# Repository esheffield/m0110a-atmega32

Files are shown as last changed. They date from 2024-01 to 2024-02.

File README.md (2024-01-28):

# m0110a-atmega32

## Background
This repo contains the schematic, pcb, and code for a drop-in replacement module for the controller in the Macintosh Plus m0110a keyboard. This controller is often damage or destroyed thanks to Apple's bizarre decision to use a cable that that *looks* like a telephone handset cable and uses the same connectors but is *wired differently*. If a user tried to use a phone handset cable in place of the original, this would feed reversed polarity power to the controller and kill it.

This replacement is based on the ATMega32 microcontroller. This controller was chosen due to the high number of GPIO pins available. The keyboard uses most of these, with a 10 x 8 matrix, four additional lines for Shift, Caps Lock, Command, and Option keys, and two communication lines for a total of 24 required lines. To aid in debugging if necessary in the future, the dedicated serial TxD and RxD lines are reserved and broken out to an optional header on the module.

The module also provides a standard 6-pin ISP connection. Thanks to the layout of keyboard, it's possible to access the ISP and Serial headers by removing the spacebar.

## Limitations
At this time, this module will only work in the m0110a keyboard as included with the Macintosh Plus. I don't know if the 128 / 512 keyboard and numeric keypad use the same controller. I understand that the keypad in particular has to act as a intermediary between the keyboard and Mac. I expect this work could be adapted, but at the least would require updated code if not changes to the hardware itself.

## License

The design and code are licensed under Apache 2.0.

## Attribution and Thanks

The code for communication with the Macintosh is based on the work of Tomasz Rękawek (https://github.com/trekawek), specifically his project adapting a PS2 keyboard to a Mac Plus (https://github.com/trekawek/mac-plus-ps2). Many thanks to Tomasz for his valuable work!

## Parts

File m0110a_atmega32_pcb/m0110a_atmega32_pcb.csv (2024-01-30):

# | Reference | Qty | Value | Footprint | DNP
1 | C1, C2 | 2 | 18p | Capacitor_SMD:C_0201_0603Metric
2 | C3 | 1 | 1u | Capacitor_SMD:C_0201_0603Metric
3 | J1 | 1 | Conn_01x40_Pin | m0110a:Conn_2.54_W15.24mm
4 | J2 | 1 | ISP | Connector_PinHeader_2.54mm:PinHeader_2x03_P2.54mm_Vertical
5 | J3 | 1 | Serial | Connector_PinHeader_2.54mm:PinHeader_1x02_P2.54mm_Vertical
6 | R1 | 1 | 4k7 | Resistor_SMD:R_0201_0603Metric
7 | U2 | 1 | ATmega32A-M | Package_DFN_QFN:QFN-44-1EP_7x7mm_P0.5mm_EP5.2x5.2mm
8 | Y1 | 1 | 8 MHz | Crystal:Crystal_SMD_5032-2Pin_5.0x3.2mm

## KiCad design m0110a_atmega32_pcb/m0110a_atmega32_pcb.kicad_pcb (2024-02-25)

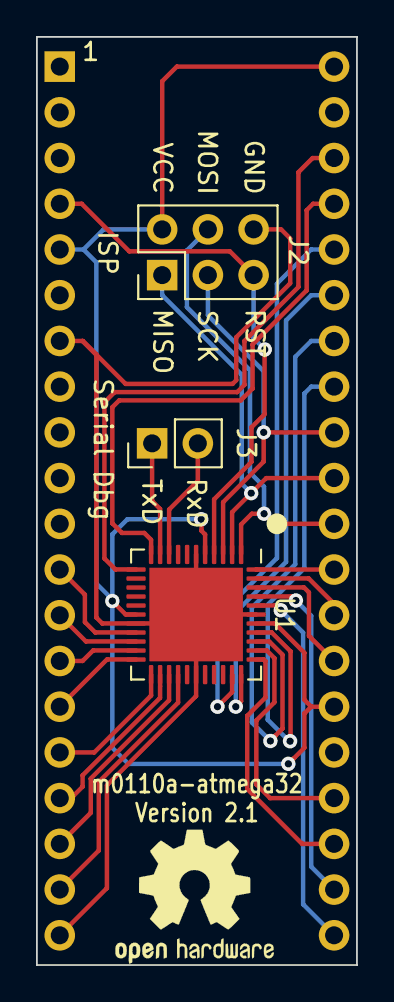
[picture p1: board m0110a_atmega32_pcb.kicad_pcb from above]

Board: 2 copper layers, 17.8 x 51.6 mm, 4 parts (0 on the bottom side), 29 nets.

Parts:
J1: Conn_01x40_Pin; Header_2.54_W15.24mm
J2: ISP; PinHeader_2x03_P2.54mm_Vertical
J3: Serial; PinHeader_1x02_P2.54mm_Vertical
U1: ATmega32A-M; QFN-44-1EP_7x7mm_P0.5mm_EP5.2x5.2mm

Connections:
+5V: J1.5, J1.26, J1.40, J2.2, U1.5 (VCC), U1.17 (VCC), U1.38 (VCC)
/CMD: J1.36, U1.32 (PA5)
/COL0: J1.19, U1.26 (PC7)
/COL1: J1.18, U1.25 (PC6)
/COL2: J1.17, U1.24 (PC5)
/COL3: J1.16, U1.23 (PC4)
/COL4: J1.15, U1.22 (PC3)
/COL5: J1.14, U1.21 (PC2)
/COL6: J1.13, U1.20 (PC1)
/COL7: J1.12, U1.19 (PC0)
/KB_CLK: J1.37, U1.11 (PD2)
/KB_DATA: J1.38, U1.12 (PD3)
/LOCK: J1.24, U1.35 (PA2)
/OPT: J1.35, U1.33 (PA4)
/ROW0: J1.21, U1.40 (PB0)
/ROW1: J1.22, U1.41 (PB1)
/ROW2: J1.27, U1.42 (PB2)
/ROW3: J1.28, U1.43 (PB3)
/ROW4: J1.29, U1.44 (PB4)
/ROW5: J1.30, J2.4, U1.1 (PB5)
/ROW6: J1.31, J2.1, U1.2 (PB6)
/ROW7: J1.32, J2.3, U1.3 (PB7)
/ROW8: J1.33, U1.37 (PA0)
/ROW9: J1.34, U1.36 (PA1)
/RXD: J3.2, U1.9 (PD0)
/SHIFT: J1.23, U1.34 (PA3)
/TXD: J3.1, U1.10 (PD1)
GNDREF: J1.7, J1.20, J2.6, U1.6 (GND), U1.18 (GND), U1.28 (GND), U1.39 (GND), U1.45 (GND)
RESET: J1.4, J2.5, U1.4 (~RESET)

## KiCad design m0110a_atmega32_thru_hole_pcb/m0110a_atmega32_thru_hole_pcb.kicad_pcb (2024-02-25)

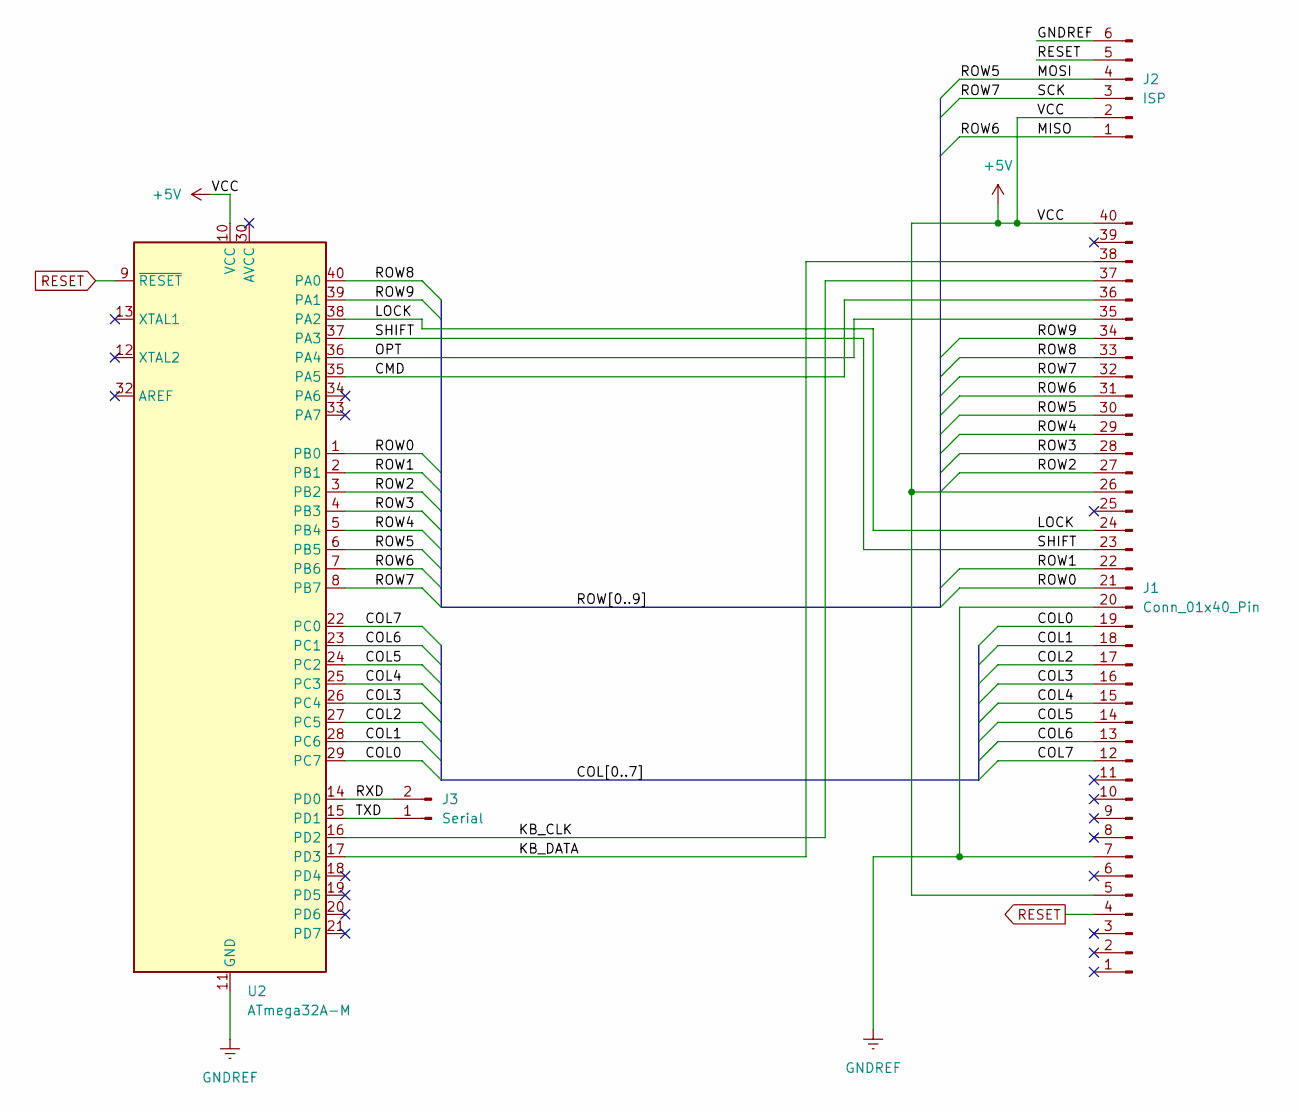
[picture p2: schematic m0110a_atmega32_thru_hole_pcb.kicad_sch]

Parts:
J1: Conn_01x40_Pin; Header_2.54_W15.24mm
J2: ISP; PinHeader_2x03_P2.54mm_Vertical
J3: Serial; PinHeader_1x02_P2.54mm_Vertical
U2: ATmega32A-M; DIP-40_W15.24mm

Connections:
+5V: J1.5, J1.26, J1.40, J2.2, U2.10 (VCC)
/CMD: J1.36, U2.35 (PA5)
/COL0: J1.19, U2.29 (PC7)
/COL1: J1.18, U2.28 (PC6)
/COL2: J1.17, U2.27 (PC5)
/COL3: J1.16, U2.26 (PC4)
/COL4: J1.15, U2.25 (PC3)
/COL5: J1.14, U2.24 (PC2)
/COL6: J1.13, U2.23 (PC1)
/COL7: J1.12, U2.22 (PC0)
/KB_CLK: J1.37, U2.16 (PD2)
/KB_DATA: J1.38, U2.17 (PD3)
/LOCK: J1.24, U2.38 (PA2)
/OPT: J1.35, U2.36 (PA4)
/ROW0: J1.21, U2.1 (PB0)
/ROW1: J1.22, U2.2 (PB1)
/ROW2: J1.27, U2.3 (PB2)
/ROW3: J1.28, U2.4 (PB3)
/ROW4: J1.29, U2.5 (PB4)
/ROW5: J1.30, J2.4, U2.6 (PB5)
/ROW6: J1.31, J2.1, U2.7 (PB6)
/ROW7: J1.32, J2.3, U2.8 (PB7)
/ROW8: J1.33, U2.40 (PA0)
/ROW9: J1.34, U2.39 (PA1)
/RXD: J3.2, U2.14 (PD0)
/SHIFT: J1.23, U2.37 (PA3)
/TXD: J3.1, U2.15 (PD1)
GNDREF: J1.7, J1.20, J2.6, U2.11 (GND), U2.31 (GND)
RESET: J1.4, J2.5, U2.9 (~RESET)

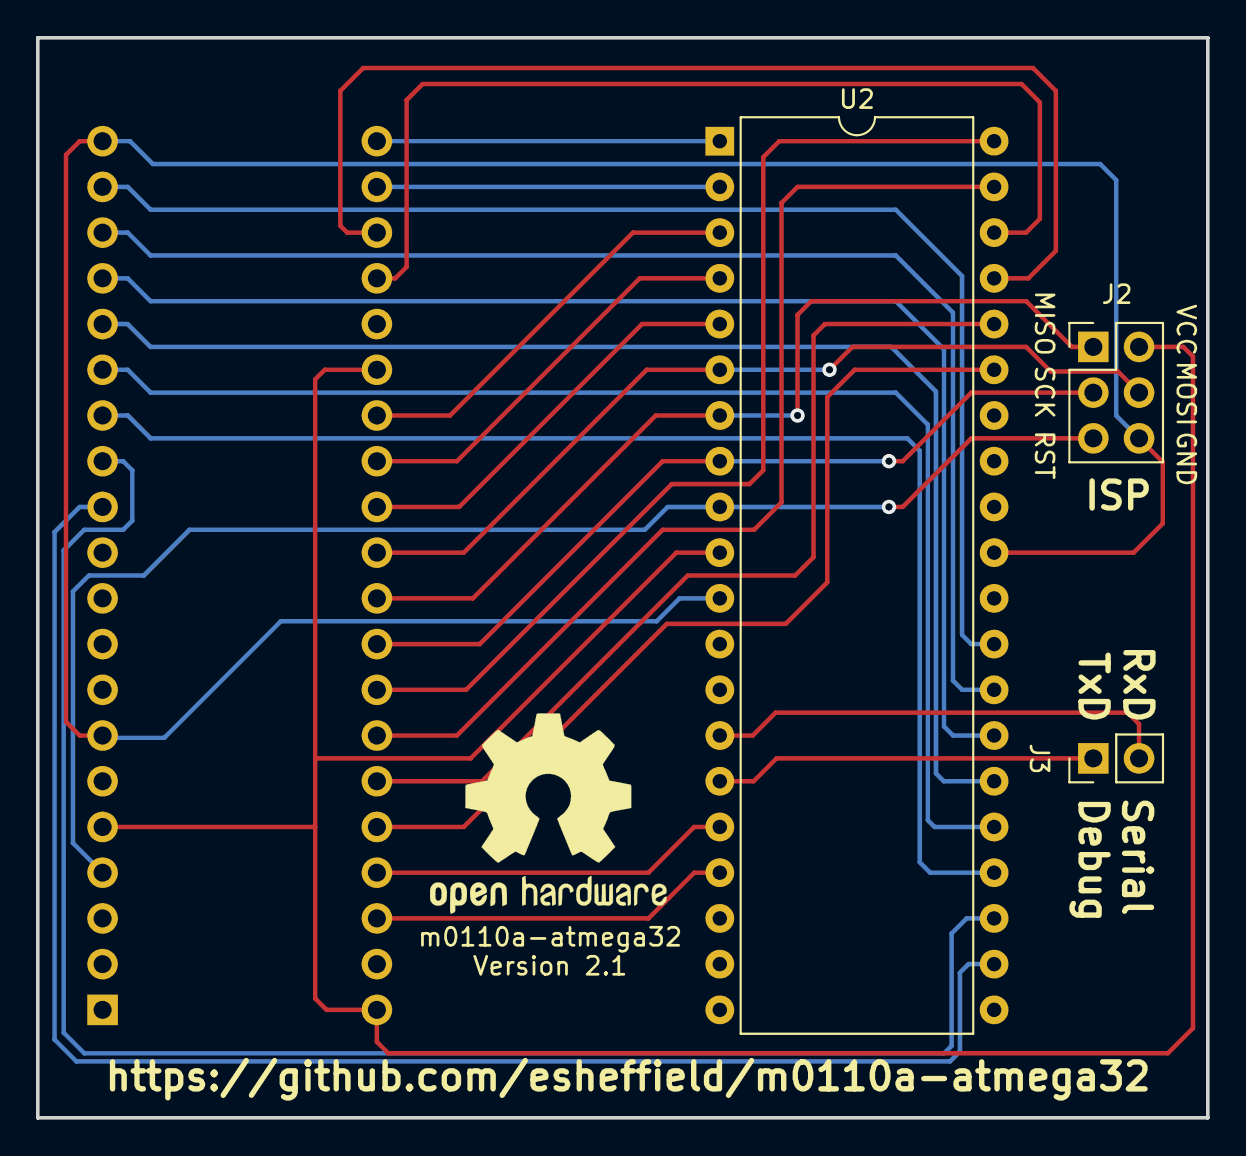
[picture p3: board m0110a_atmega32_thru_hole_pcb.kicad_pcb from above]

Board: 2 copper layers, 65.0 x 60.0 mm, 4 parts (1 on the bottom side), 29 nets.

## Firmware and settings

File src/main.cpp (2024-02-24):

#include <Arduino.h>

#include <M0110aKeyboard.hpp>
#include <KeyboardProtocol.hpp>
#include <pins.hpp>

void inquiry();

M0110aKeyboard keyboard;
KeyboardProtocol mac;

void setup()
{
#ifdef SERIAL_DEBUG
    Serial.begin(9600);
    Serial.println("Initializing...");
#endif

    keyboard.begin(ROW_PINS, COL_PINS, MOD_PINS);
    mac.begin(DATA_PIN, CLK_PIN);
}

void loop()
{
    byte cmd = mac.readCmd();

#ifdef SERIAL_DEBUG
    Serial.printf("Command: %02X\n\r", cmd);
#endif

    switch (cmd)
    {
    case INQUIRY_CMD:
    {
#ifdef SERIAL_DEBUG
        Serial.println("Inquiry");
#endif
        inquiry();
        break;
    }
    case INSTANT_CMD:
    {
#ifdef SERIAL_DEBUG
        Serial.println("Instant");
#endif
        uint16_t key = keyboard.getScanCode();
#ifdef SERIAL_DEBUG
        Serial.printf("\tSending: %02X\n\r", key);
#endif
        mac.sendKey(key);
        break;
    }
    case MODEL_CMD:
    {
#ifdef SERIAL_DEBUG
        Serial.println("Model");
#endif
        mac.sendByte(MODEL_ID);
        break;
    }
    case TEST_CMD:
    {
#ifdef SERIAL_DEBUG
        Serial.println("Test");
#endif
        mac.sendByte(KB_ACK);
        break;
    }
    }
}

void inquiry()
{
    unsigned long start = millis();
    while ((millis() - start) < 250)
    {
        int key = keyboard.getScanCode();
        if (key != KEY_NONE)
        {
#ifdef SERIAL_DEBUG
            Serial.printf("\tSending: %02X\n\r", key);
#endif
            mac.sendKey(key);
            return;
        }
    }
#ifdef SERIAL_DEBUG
    Serial.printf("\tSending: %02X\n\r", KEY_NONE);
#endif
    mac.sendKey(KEY_NONE);
}

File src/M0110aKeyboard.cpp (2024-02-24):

#include <Arduino.h>
#include <M0110aKeyboard.hpp>

void M0110aKeyboard::begin(byte *row_pins, byte *col_pins, byte *mod_pins)
{
    this->row_pins = row_pins;
    this->col_pins = col_pins;
    this->mod_pins = mod_pins;

    // Initialize ROW_COUNT to INPUTs (HI-Z)
    // ROW_COUNT are active LOV, but inactive lines wil be HI-Z, not HIGH
    for (int i = 0; i < ROW_COUNT; i++)
    {
        pinMode(row_pins[i], INPUT);
    };

    // The columns are already pulled up externally on the Mac Plus keyboard
    // so no need for internal pullups here
    for (int i = 0; i < COL_COUNT; i++)
    {
        pinMode(col_pins[i], INPUT);
    };

    // The modifier keys on the other hand do NOT have external pullups
    for (int i = 0; i < MOD_COUNT; i++)
    {
        pinMode(mod_pins[i], INPUT_PULLUP);
    };
}

void M0110aKeyboard::reset() {
    for(int i = 0; i < ROW_COUNT; i++) {
        key_states[i] = 0;
    }

    opt_state = 0;
    cmd_state = 0;
    lck_state = 0;
    shf_state = 0;
}

uint16_t M0110aKeyboard::getScanCode()
{
    uint16_t key_code = KEY_NONE;

    byte mod_values = readMods();

    // Code is getting printed from check_modifier for now, in future will add the return to the buffer
    key_code = check_modifier((OPT_MASK & mod_values), KEY_OPT, &opt_state);
    if (key_code) return key_code;

    key_code = check_modifier((CMD_MASK & mod_values), KEY_CMD, &cmd_state);
    if (key_code) return key_code;

    key_code = check_modifier((LCK_MASK & mod_values), KEY_LOCK, &lck_state);
    if (key_code) return key_code;

    key_code = check_modifier((SHF_MASK & mod_values), KEY_SHIFT, &shf_state);
    if (key_code) return key_code;

    for (int row = 0; row < ROW_COUNT; row++)
    {
        pinMode(row_pins[row], OUTPUT);
        digitalWrite(row_pins[row], LOW);
        byte col_values = readCols();
        pinMode(row_pins[row], INPUT);

        for (int col = 0; col < COL_COUNT; col++)
        {
            byte mask = 1 << col;
            key_code = KEYMAP[row][col];
            byte last_key_state = key_states[row] & mask;
            byte cur_key_state = col_values & mask;

            // Update current state
            key_states[row] = (key_states[row] & ~mask) | cur_key_state;

            if (last_key_state && !cur_key_state) // key transition from pressed to released
            {
                // Set bit 7 to indicate key release
                key_code |= KEY_TXN_UP;
            }
            else if (cur_key_state == last_key_state) // key state unchanged
            {
                key_code = KEY_NONE;
            }

            if (key_code != KEY_NONE)
            {
                if (isKeypadShift(row, col))
                {
                    return NUMPAD2 | key_code;
                }
                else if (isKeypad(row, col))
                {
                    return NUMPAD | key_code;
                }

                return key_code;
            }
        }
    }

    return KEY_NONE;
}

byte M0110aKeyboard::readMods()
{
    byte mods = 0;

    mods |= digitalRead(mod_pins[CMD_PIN_IDX]) << 3;
    mods |= digitalRead(mod_pins[OPT_PIN_IDX]) << 2;
    mods |= digitalRead(mod_pins[LCK_PIN_IDX]) << 1;
    mods |= digitalRead(mod_pins[SHF_PIN_IDX]);

    return ~mods & 0x0F;
}

byte M0110aKeyboard::readCols()
{
    byte cols = 0;
    for (int i = COL_COUNT - 1; i >= 0; i--)
    {
        cols |= digitalRead(col_pins[i]) << i;
    }

    return ~cols;
}

// Check if the key is a keypad or arrow key needing a "keypad" prefix (0x79)
bool M0110aKeyboard::isKeypad(byte row, byte col)
{
    uint16_t kp_row = KEYPAD_MAP_BY_COL[col];
    uint16_t active_row = (1 << row);

#ifdef SERIAL_DEBUG
    Serial.printf("(%d, %d)\n\r", row, col);
    Serial.printf("active_row: %02X\tkp_row: %02X\n\r", active_row, kp_row);
#endif

    return (active_row & kp_row);
}

// Check if the key is one of the keypad keys that needs a "shift" prefix (0x71)
bool M0110aKeyboard::isKeypadShift(byte row, byte col)
{
    return (col == 5 && (row == 9)) || (col == 6 && (row == 2 || row == 3 || row == 4));
}

// Checks if a given modifier key (Option, Command, Shift, Shift-Lock)
// has transitioned and returns the key_code with transition flag if so
byte M0110aKeyboard::check_modifier(byte masked_value, byte mod_key_code, byte *state)
{
    byte key_code = mod_key_code;
    if (!masked_value && *state)
    {
        key_code |= KEY_TXN_UP;
        *state = 0;
    }
    else if (masked_value && !(*state))
    {
        *state = 1;
    }
    else
    {
        key_code = KEY_NONE;
    }

    return key_code;
}

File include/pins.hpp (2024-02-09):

#include <Arduino.h>

#ifndef PINS_HPP
#define PINS_HPP

#define CLK_PIN PIN_PD2
#define DATA_PIN PIN_PD3

#define CMD_PIN PIN_PA5
#define OPT_PIN PIN_PA4
#define LCK_PIN PIN_PA2
#define SHF_PIN PIN_PA3

byte ROW_PINS[] = {PIN_PB0, PIN_PB1, PIN_PB2, PIN_PB3, PIN_PB4, PIN_PB5, PIN_PB6, PIN_PB7, PIN_PA0, PIN_PA1};
byte COL_PINS[] = {PIN_PC7, PIN_PC6, PIN_PC5, PIN_PC4, PIN_PC3, PIN_PC2, PIN_PC1, PIN_PC0};
byte MOD_PINS[] = {CMD_PIN, OPT_PIN, LCK_PIN, SHF_PIN};

#endif

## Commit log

2024-01-28 Rearrange some pins for easier PCB layout
2024-01-28 Add schematic and PCB design
    [m0110a_atmega32_pcb.kicad_pcb, m0110a_atmega32_pcb.kicad_sch]
2024-01-28 Update ignore for KiCAD files
2024-01-30 Updated PCB to use more readily available parts
    [m0110a_atmega32_pcb.csv, m0110a_atmega32_pcb.kicad_pcb, m0110a_atmega32_pcb.kicad_sch]
2024-02-05 Fixed shift locking when certain numpad keys are pressed
    Added thru-hold PCB design
    [m0110a_atmega32_thru_hole_pcb.kicad_pcb, m0110a_atmega32_thru_hole_pcb.kicad_sch]
2024-02-05 Switched from external to internal clocking
    [m0110a_atmega32_pcb.kicad_pcb, m0110a_atmega32_pcb.kicad_sch, m0110a_atmega32_thru_hole_pcb.kicad_pcb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]
2024-02-09 Removed unneeded resistor and ground connections
    [m0110a_atmega32_pcb.kicad_pcb, m0110a_atmega32_pcb.kicad_sch, m0110a_atmega32_thru_hole_pcb.kicad_pcb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]
2024-02-09 Swapped data and clk for easier layout. V 2.1
    [m0110a_atmega32_pcb.kicad_pcb, m0110a_atmega32_pcb.kicad_sch, m0110a_atmega32_thru_hole_pcb.kicad_pcb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]
2024-02-15 Added gerbers (PCBWay rules)
    [m0110a_atmega32_pcb-B_Cu.gbr, m0110a_atmega32_pcb-B_Mask.gbr, m0110a_atmega32_pcb-B_Paste.gbr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]
2024-02-24 KP equal fix, serial debug cleanups
    - KP equal needs a SHIFT prefix code as well, wasn't listed in the Mac docs
    - Wrapped all debugging prints with ifdefs on SERIAL_DEBUG
    - Added commented out SERIAL_DEBUG definition to platformio.ini for easy
    reference
    Note: I attempted to created wrappers around the Serial.printX
    functions, but they aren't actually variadic and would have meant
    defining wrappers for every variant used so just stuck with directly
    using Serial.printX wrapped with ifdefs. Ugly, but works.
    [KeyboardProtocol.cpp, M0110aKeyboard.cpp, main.cpp]
2024-02-25 Updated PCBs
    - Increased hole size on 40 pin connector to accomodate standard pin headers
    - Moved ISP connector on SMD board to clear support under spacebar
    - Improved labeling on thru-hole board for ISP connector
    [m0110a_atmega32_pcb-B_Cu.gbr, m0110a_atmega32_pcb-B_Mask.gbr, m0110a_atmega32_pcb-B_Paste.gbr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]
